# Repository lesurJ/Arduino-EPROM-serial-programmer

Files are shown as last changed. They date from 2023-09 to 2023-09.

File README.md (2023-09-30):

# Arduino-EPROM-serial-programmer

A project to program vintage EPROMs with modern Python and Arduino.

/!\ Work in progress. New version will include voltage regulators to generate the required programming voltages.

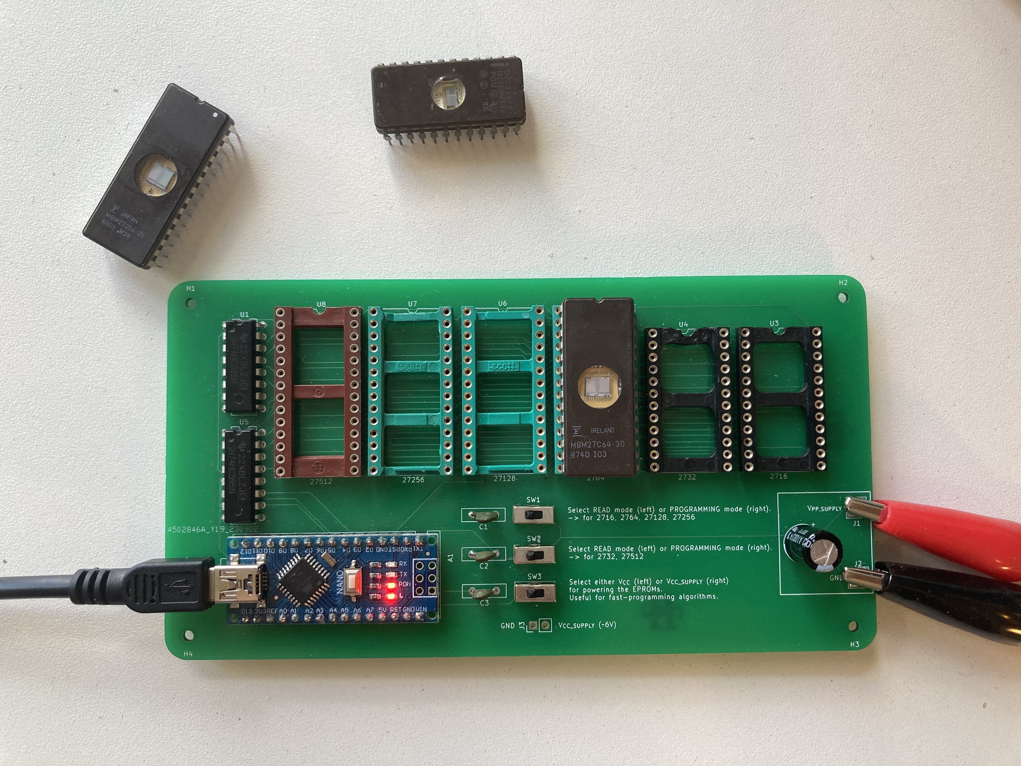
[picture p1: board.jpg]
board


## Introduction

EPROMs are found in many old devices (scopes, data logger, computer). They are very good at long term data retention. And the good thing is they can be erased and re-programmed easily (with a bit of hardware).

Unfortunately, the devices for reading and programming EPROMs are usually expensive as they are universal: they can program almost all EPROMs. I really don't need such universal programmers as I use EPROMs for my hobby and I have only a few different types of EPROM.

## Description

A serial connection is opened between the computer and the arduino. This connection is used to transfer commands (read or write) and data (memory contents or machine code).

The circuit schematic is located [here](EPROM_FLASHER/Schematic.pdf).
It is based on an Arduino Nano, two 8-bit serial-in parallel-out shift registers (ref. 74HC595) and some passive components (condensator, 3 capacitors, 3 switches). Two soldering pads are present for powering the "program pin" of the EPROMs during a write operation.

The address lines of the EPROMs are driven by the shift registers whereas their data lines are driven by 8 Arduino pins.

## Installation

* Flash the [arduino program](arduino_programmer/arduino_programmer.ino) into the Arduino Nano. Use the Arduino IDE for this.
* Get yourself the PCB. You can directly upload the [zip file](EPROM_FLASHER/GERBER/EPROM_FLASHER.zip) to PCB production services.
* Solder the components on the PCB.
* Install a SINGLE EPROM on the board.

## Usage

* Connect the Arduino to the computer.
* For reading the EPROM run

```sh
python3 main.py -t X
```

where **X** is the memory type code (see [supported EPROMs](#supported-eproms)). The EPROM contents will be written in the file [epromContents_before.txt](epromContents_before.txt).

* For programming the EPROM run

```python
python3 main.py -t X -f path-to-the-machine-code-txt
```

where **X** is the memory type code (see [supported EPROMs](#supported-eproms)) and the path is indicating where you machine code is located.
Before programming, the program will pause and ask you to apply the programming voltage on the external supply pad. It will resume once you press the ENTER key.

## Example

A machine code example is located [here](programs/machineCode.txt). It is not a binary file but a txt files containing the program bytes on separate lines.

&rarr; If I want to read the contents of a NEC 2732D EPROM, I run

```sh
python3 main.py -t 32
```

&rarr; If I want to write the program [programs/machineCode.txt](programs/machineCode.txt) in the NEC 2732D EPROM, I run

```sh
python3 main.py -t 32 -f programs/machineCode.txt
```

I can see the contents of the EPROM in the file [epromContents_before.txt](epromContents_before.txt).

## Supported EPROMs

|EPROM|memory code|Memory Size [bytes]|
|---|---|---|
|27x16|16|2048|
|27x32|32|4096|
|27x64|64|8192|
|27x128|128|16384|
|27x256|256|32768|
|27x512|512|65536|

## Warning

DO NOT HOT-SWAP EPROM!

READ CAREFULLY THE DATASHEET FOR YOUR EPROM TO CHECK THE PROGRAMMING PROCEDURE AND VOLTAGE!

## Note

This project was made with components I had laying around. I didn't have a ZIF (Zero Insertion Force) socket for the EPROMs and this is the reason why I used 6 different sockets.

To keep the board simple, the programming voltage is not generated on the board, but  by an external power supply whose wires are attached to the power supply terminals.

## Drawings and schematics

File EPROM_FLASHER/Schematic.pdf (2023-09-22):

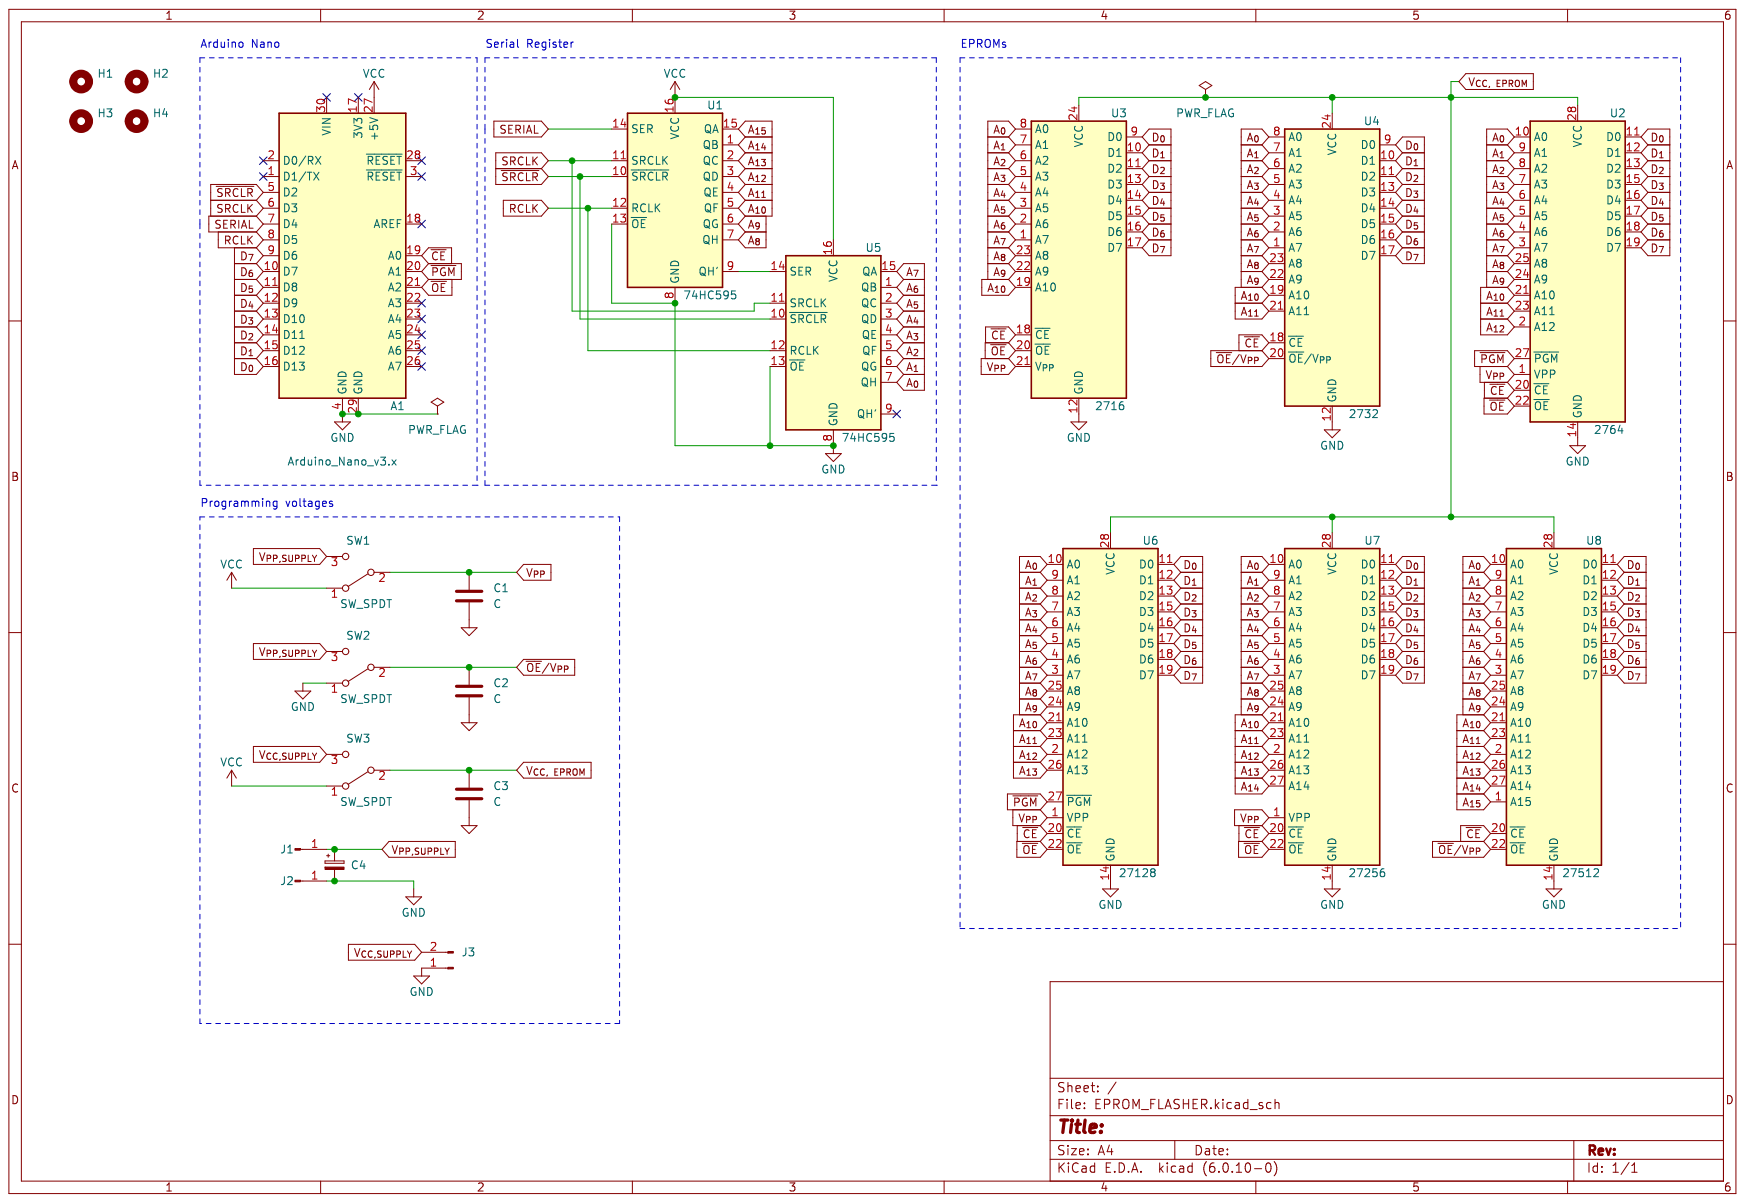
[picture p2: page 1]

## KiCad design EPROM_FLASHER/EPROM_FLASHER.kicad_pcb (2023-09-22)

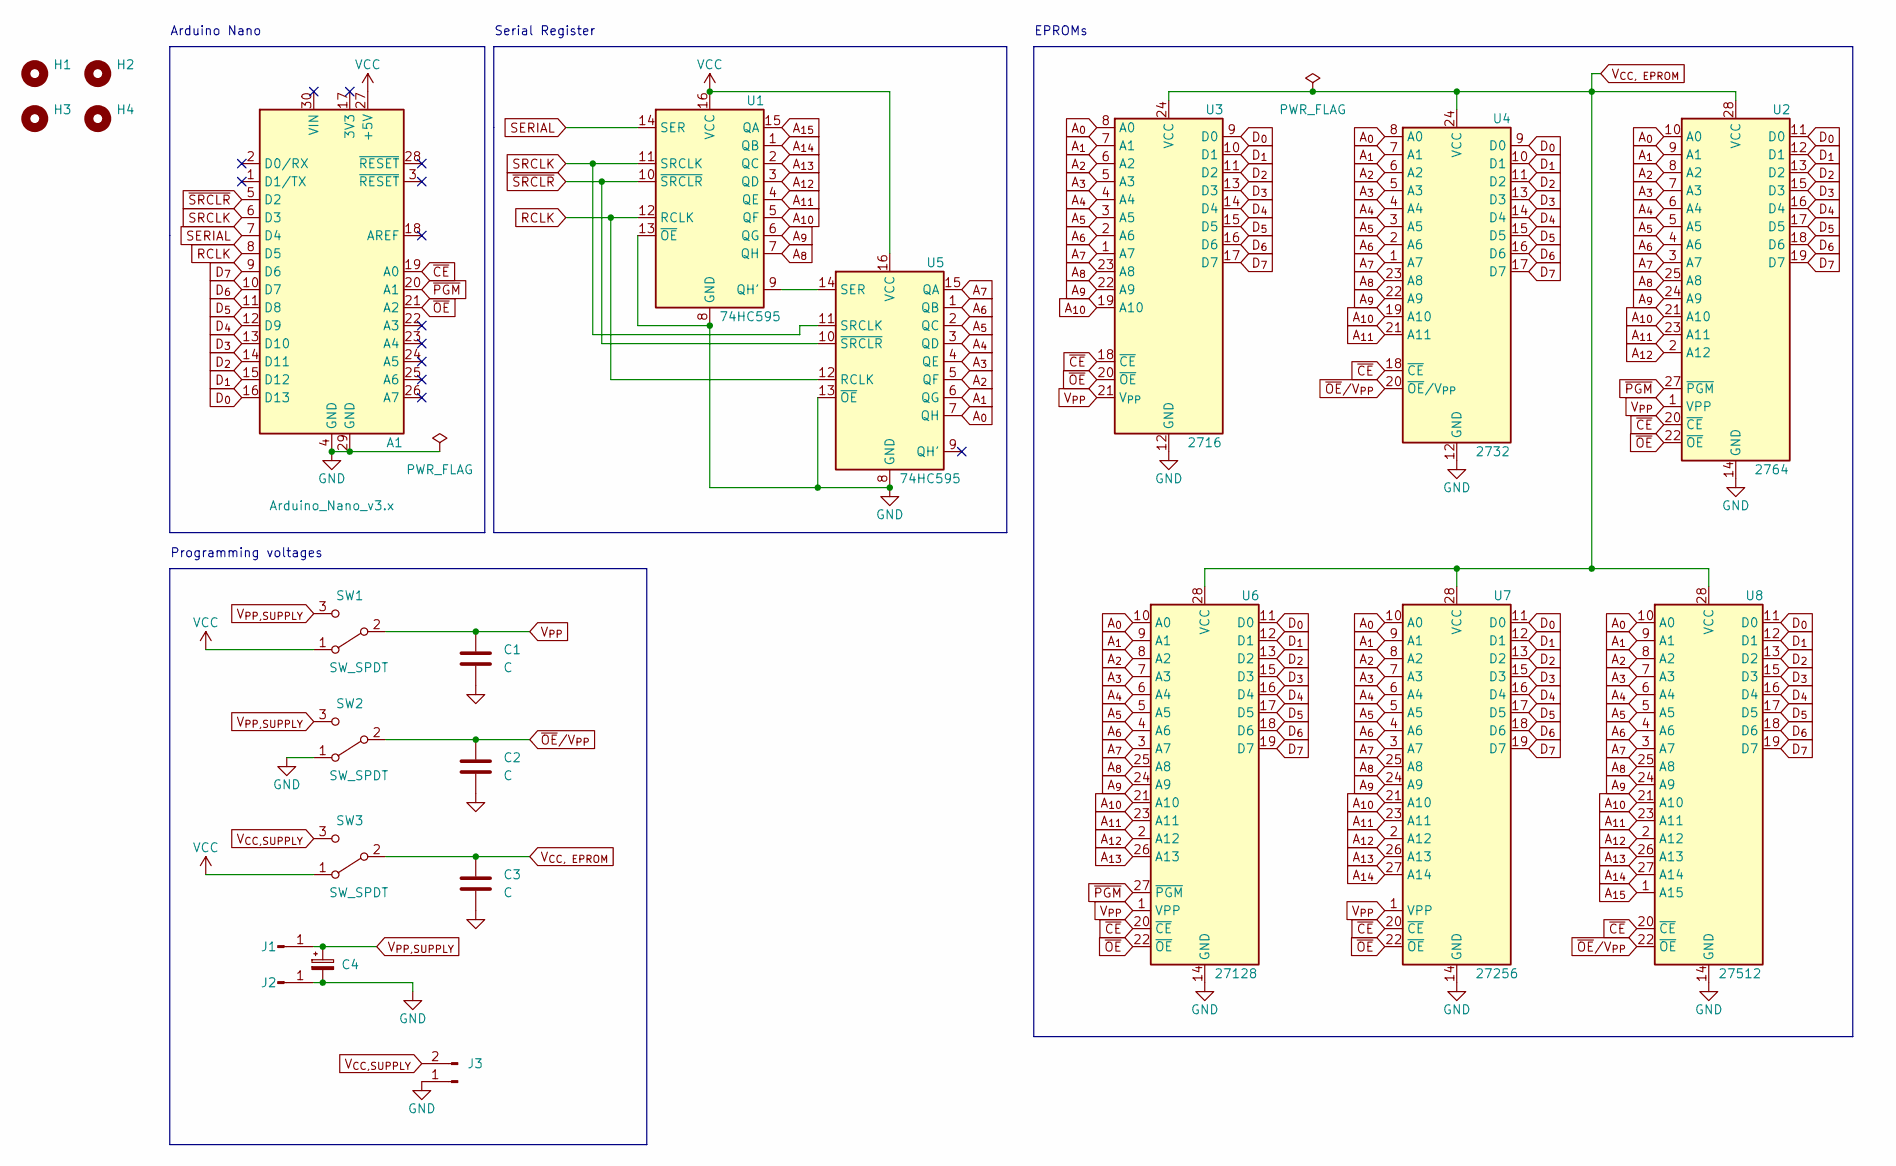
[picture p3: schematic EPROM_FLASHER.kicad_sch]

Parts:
A1: Arduino_Nano_v3.x; Arduino_Nano
C1, C2, C3: C; C_Disc_D9.0mm_W2.5mm_P5.00mm
C4: C_Polarized_Small; CP_Radial_D8.0mm_P3.50mm
H1, H2, H3, H4: MountingHole; MountingHole_2.2mm_M2
J1, J2: Conn_01x01_Male; TestPoint_Pad_4.0x4.0mm
J3: Conn_01x02_Male; PinHeader_1x02_P2.54mm_Vertical
SW1, SW2, SW3: SW_SPDT; SPDT_p2.54mm
U1, U5: 74HC595; DIP-16_W7.62mm
U2: 2764; DIP-28_W15.24mm
U3: 2716; DIP-24_W15.24mm
U4: 2732; DIP-24_W15.24mm
U6: 27128; DIP-28_W15.24mm
U7: 27256; DIP-28_W15.24mm
U8: 27512; DIP-28_W15.24mm

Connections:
A_{0}: U2.10 (A0), U3.8 (A0), U4.8 (A0), U5.7 (QH), U6.10 (A0), U7.10 (A0), U8.10 (A0)
A_{1}: U2.9 (A1), U3.7 (A1), U4.7 (A1), U5.6 (QG), U6.9 (A1), U7.9 (A1), U8.9 (A1)
A_{2}: U2.8 (A2), U3.6 (A2), U4.6 (A2), U5.5 (QF), U6.8 (A2), U7.8 (A2), U8.8 (A2)
A_{3}: U2.7 (A3), U3.5 (A3), U4.5 (A3), U5.4 (QE), U6.7 (A3), U7.7 (A3), U8.7 (A3)
A_{4}: U2.6 (A4), U3.4 (A4), U4.4 (A4), U5.3 (QD), U6.6 (A4), U7.6 (A4), U8.6 (A4)
A_{5}: U2.5 (A5), U3.3 (A5), U4.3 (A5), U5.2 (QC), U6.5 (A5), U7.5 (A5), U8.5 (A5)
A_{6}: U2.4 (A6), U3.2 (A6), U4.2 (A6), U5.1 (QB), U6.4 (A6), U7.4 (A6), U8.4 (A6)
A_{7}: U2.3 (A7), U3.1 (A7), U4.1 (A7), U5.15 (QA), U6.3 (A7), U7.3 (A7), U8.3 (A7)
A_{8}: U1.7 (QH), U2.25 (A8), U3.23 (A8), U4.23 (A8), U6.25 (A8), U7.25 (A8), U8.25 (A8)
A_{9}: U1.6 (QG), U2.24 (A9), U3.22 (A9), U4.22 (A9), U6.24 (A9), U7.24 (A9), U8.24 (A9)
A_{10}: U1.5 (QF), U2.21 (A10), U3.19 (A10), U4.19 (A10), U6.21 (A10), U7.21 (A10), U8.21 (A10)
A_{11}: U1.4 (QE), U2.23 (A11), U4.21 (A11), U6.23 (A11), U7.23 (A11), U8.23 (A11)
A_{12}: U1.3 (QD), U2.2 (A12), U6.2 (A12), U7.2 (A12), U8.2 (A12)
A_{13}: U1.2 (QC), U6.26 (A13), U7.26 (A13), U8.26 (A13)
A_{14}: U1.1 (QB), U7.27 (A14), U8.27 (A14)
A_{15}: U1.15 (QA), U8.1 (A15)
D_{0}: A1.16 (D13), U2.11 (D0), U3.9 (D0), U4.9 (D0), U6.11 (D0), U7.11 (D0), U8.11 (D0)
D_{1}: A1.15 (D12), U2.12 (D1), U3.10 (D1), U4.10 (D1), U6.12 (D1), U7.12 (D1), U8.12 (D1)
D_{2}: A1.14 (D11), U2.13 (D2), U3.11 (D2), U4.11 (D2), U6.13 (D2), U7.13 (D2), U8.13 (D2)
D_{3}: A1.13 (D10), U2.15 (D3), U3.13 (D3), U4.13 (D3), U6.15 (D3), U7.15 (D3), U8.15 (D3)
D_{4}: A1.12 (D9), U2.16 (D4), U3.14 (D4), U4.14 (D4), U6.16 (D4), U7.16 (D4), U8.16 (D4)
D_{5}: A1.11 (D8), U2.17 (D5), U3.15 (D5), U4.15 (D5), U6.17 (D5), U7.17 (D5), U8.17 (D5)
D_{6}: A1.10 (D7), U2.18 (D6), U3.16 (D6), U4.16 (D6), U6.18 (D6), U7.18 (D6), U8.18 (D6)
D_{7}: A1.9 (D6), U2.19 (D7), U3.17 (D7), U4.17 (D7), U6.19 (D7), U7.19 (D7), U8.19 (D7)
GND: A1.4 (GND), A1.29 (GND), C1.2, C2.2, C3.2, C4.2, J2.1, J3.1, SW2.1 (A), U1.8 (GND), U1.13 (~OE), U2.14 (GND), U3.12 (GND), U4.12 (GND), U5.8 (GND), U5.13 (~OE), U6.14 (GND), U7.14 (GND), U8.14 (GND)
unnamed: U1.9 (QH'), U5.14 (SER)
RCLK: A1.8 (D5), U1.12 (RCLK), U5.12 (RCLK)
SERIAL: A1.7 (D4), U1.14 (SER)
SRCLK: A1.6 (D3), U1.11 (SRCLK), U5.11 (SRCLK)
VCC: A1.27 (+5V), SW1.1 (A), SW3.1 (A), U1.16 (VCC), U5.16 (VCC)
V_{CC, EPROM}: C3.1, SW3.2 (B), U2.28 (VCC), U3.24 (VCC), U4.24 (VCC), U6.28 (VCC), U7.28 (VCC), U8.28 (VCC)
V_{CC,SUPPLY}: J3.2, SW3.3 (C)
V_{PP,SUPPLY}: C4.1, J1.1, SW1.3 (C), SW2.3 (C)
V_{PP}: C1.1, SW1.2 (B), U2.1 (VPP), U3.21 (V_{PP}), U6.1 (VPP), U7.1 (VPP)
~CE: A1.19 (A0), U2.20 (~CE), U3.18 (~CE), U4.18 (~CE), U6.20 (~CE), U7.20 (~CE), U8.20 (~CE)
~OE: A1.21 (A2), U2.22 (~OE), U3.20 (~OE), U6.22 (~OE), U7.22 (~OE)
~OE/V_{PP}: C2.1, SW2.2 (B), U4.20 (~OE/V_{PP}), U8.22 (~OE)
~PGM: A1.20 (A1), U2.27 (~PGM), U6.27 (~PGM)
~SRCLR: A1.5 (D2), U1.10 (~SRCLR), U5.10 (~SRCLR)

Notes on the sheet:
EPROMs
Serial Register
Programming voltages
Arduino Nano

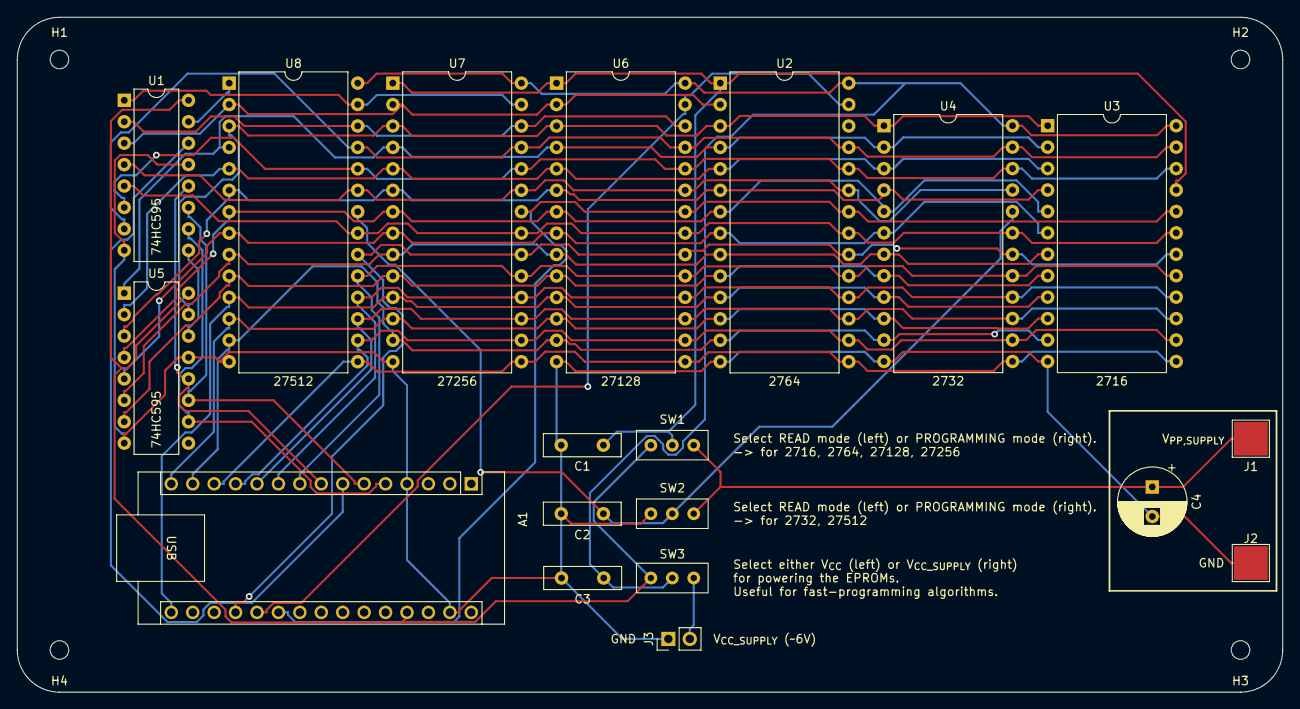
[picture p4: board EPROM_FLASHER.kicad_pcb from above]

Board: 2 copper layers, 150.0 x 80.0 mm, 23 parts (0 on the bottom side), 39 nets.

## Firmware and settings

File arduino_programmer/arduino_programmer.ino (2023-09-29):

const int nSRCLR_pin = 2;
const int SRCLK_pin = 3;
const int SERIAL_pin = 4;
const int RCLK_pin = 5;
const int msb_pin = 6;
const int lsb_pin = 13;

const int nCE_PIN = A0;
const int nPGM_PIN = A1;
const int nOE_PIN = A2;

const unsigned long baudrate = 115200;
const char start_of_message = '<';
const char end_of_message = '>';
const int read_mode = 0;
const int write_mode = 1;

const int chunk_size = 16;
byte data_buffer[chunk_size];

// === FUNCTIONS ===

void setAddress(long address)
{
    digitalWrite(RCLK_pin, LOW);
    shiftOut(SERIAL_pin, SRCLK_pin, LSBFIRST, (byte)address);
    shiftOut(SERIAL_pin, SRCLK_pin, LSBFIRST, address >> 8);
    digitalWrite(RCLK_pin, HIGH);
}

void changeDataPinMode(int mode)
{
    if (mode == read_mode)
    {
        for (int pin = msb_pin; pin <= lsb_pin; pin++)
        {
            pinMode(pin, INPUT);
        }
    }
    else if (mode == write_mode)
    {
        for (int pin = msb_pin; pin <= lsb_pin; pin++)
        {
            pinMode(pin, OUTPUT);
        }
    }
}

void changeControlPinLevels(int mode, int eprom_type)
{
    if (mode == read_mode)
    {
        digitalWrite(nCE_PIN, LOW);
        digitalWrite(nOE_PIN, LOW);
        digitalWrite(nPGM_PIN, HIGH);
    }
    else
    {
        switch (eprom_type)
        {
        case 16:
            digitalWrite(nOE_PIN, HIGH);
            digitalWrite(nCE_PIN, LOW);
            break;

        case 32:
            digitalWrite(nCE_PIN, HIGH);
            break;

        case 64:
            digitalWrite(nCE_PIN, LOW);
            digitalWrite(nOE_PIN, HIGH);
            digitalWrite(nPGM_PIN, HIGH);
            break;

        case 128:
            digitalWrite(nCE_PIN, LOW);
            digitalWrite(nOE_PIN, HIGH);
            digitalWrite(nPGM_PIN, HIGH);
            break;

        case 256:
            digitalWrite(nCE_PIN, HIGH);
            digitalWrite(nOE_PIN, HIGH);
            break;

        case 512:
            digitalWrite(nCE_PIN, HIGH);
            break;
        }
    }
}

void generateProgramPulse(int eprom_type)
{
    switch (eprom_type)
    {
    case 16:
        digitalWrite(nCE_PIN, HIGH);
        delay(50);
        digitalWrite(nCE_PIN, LOW);
        break;

    case 32:
        digitalWrite(nCE_PIN, LOW);
        delay(50);
        digitalWrite(nCE_PIN, HIGH);
        break;

    case 64:
        digitalWrite(nPGM_PIN, LOW);
        delay(50);
        digitalWrite(nPGM_PIN, HIGH);
        break;

    case 128:
        digitalWrite(nPGM_PIN, LOW);
        delayMicroseconds(100);
        digitalWrite(nPGM_PIN, HIGH);
        break;

    case 256:
        digitalWrite(nCE_PIN, LOW);
        delayMicroseconds(100);
        digitalWrite(nCE_PIN, HIGH);
        break;

    case 512:
        digitalWrite(nCE_PIN, LOW);
        delayMicroseconds(100);
        digitalWrite(nCE_PIN, HIGH);
        break;
    }
}

String waitForSerialMessage(void)
{
    String message = "";
    char current_char = ' ';
    bool received_message = false;

    while (!received_message)
    {
        while (Serial.available() > 0)
        {
            current_char = Serial.read();
            if (current_char == start_of_message)
            {
                message = "";
            }
            else if (current_char == end_of_message)
            {
                received_message = true;
                break;
            }
            else
            {
                message += String(current_char);
            }
        }
    }
    return message;
}

byte readMemoryAtAddress(long address)
{
    setAddress(address);
    delayMicroseconds(1); // typical access time is 200ns for EPROM
    byte data = 0;
    for (int pin = msb_pin; pin <= lsb_pin; pin++)
    {
        data = (data << 1) + digitalRead(pin);
    }
    return data;
}

void readMemory(int eprom_type, long memory_size)
{
    changeDataPinMode(read_mode);
    changeControlPinLevels(read_mode, eprom_type);

    long bytes_read = 0;
    bool read_is_done = false;
    while (!read_is_done)
    {
        Serial.print(start_of_message);
        for (int addr = 0; addr < chunk_size; addr++)
        {
            byte data = readMemoryAtAddress(bytes_read + addr);
            Serial.println(data);
        }
        Serial.println(end_of_message);

        bytes_read += chunk_size;
        read_is_done = (bytes_read == memory_size);
    }
    Serial.println("<DONE>");
}

void writeMemory(int eprom_type, long program_size)
{
    changeDataPinMode(write_mode);
    changeControlPinLevels(write_mode, eprom_type);

    Serial.println("<WRITE-READY>");

    long data_index = 0;
    long current_address = 0;
    bool transfer_is_done = false;
    while (!transfer_is_done)
    {
        int rlen = Serial.readBytes(data_buffer, chunk_size);
        for (int data_addr = 0; data_addr < rlen; data_addr++)
        {
            current_address = data_index + data_addr;
            setAddress(current_address);
            delayMicroseconds(2); // typical adress and data setup time
            for (int pin = lsb_pin; pin >= msb_pin; pin--)
            {
                digitalWrite(pin, data_buffer[data_addr] & 1);
                data_buffer[data_addr] >>= 1;
            }
            generateProgramPulse(eprom_type);
        }

        data_index += rlen;
        transfer_is_done = (data_index == program_size);
        Serial.println("<CONTINUE>");
    }
    Serial.println("<DONE>");
}

// === END OF FUNCTIONS ===

void setup()
{
    Serial.begin(baudrate);

    pinMode(nSRCLR_pin, OUTPUT);
    pinMode(SRCLK_pin, OUTPUT);
    pinMode(SERIAL_pin, OUTPUT);
    pinMode(RCLK_pin, OUTPUT);
    pinMode(nCE_PIN, OUTPUT);
    pinMode(nPGM_PIN, OUTPUT);
    pinMode(nOE_PIN, OUTPUT);

    digitalWrite(nSRCLR_pin, HIGH);
    digitalWrite(nCE_PIN, LOW);
    digitalWrite(nOE_PIN, LOW);
    digitalWrite(nPGM_PIN, HIGH);

    while (!Serial)
    {
        delay(10);
    }

    Serial.println("<INIT>");
}

void loop()
{
    String message = waitForSerialMessage();
    int idx = message.indexOf("|");
    if (idx != -1)
    {
        int eprom_type = message.substring(0, idx).toInt();
        String command = message.substring(idx + 1);

        if (command.startsWith("R"))
        {
            long memory_size = command.substring(1).toInt();
            readMemory(eprom_type, memory_size);
        }
        else if (command.startsWith("W"))
        {
            long program_size = command.substring(1).toInt();
            writeMemory(eprom_type, program_size);
        }
    }
}

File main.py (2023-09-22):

import argparse
import os
import time
import difflib

from serialConnector import SerialConnector

def configureParser():
    parser = argparse.ArgumentParser(
        prog="main.py",
        description="This program read and write vintage EPROMs with the help of Arduino.",
    )
    parser.add_argument(
        "-t",
        "--memory_type",
        type=int,
        required=True,
        choices=[16, 32, 64, 128, 256, 512],
        help="the memory type code (e.g 32 for 27x32 memories)",
    )
    parser.add_argument(
        "-f",
        "--filename",
        type=str,
        help="the name of the machine code to flash on EPROM (.txt); all bytes must be on different lines.",
    )
    return parser.parse_args()

def getProgramCode(machine_code_file):
    with open(f"{machine_code_file}", "r") as f:
        lines = f.readlines()
    programCode = [int(item.strip(), 2) for item in lines]
    return (
        len(programCode),
        programCode,
    )

def saveDataToFile(data, filename):
    data = data.split(sep="\r\n")
    with open(filename, "w") as f:
        for d in data:
            if d != "":
                f.write(f"{int(d):08b}\n")

def readMemory(memoryType, filename):
    print("> Reading EPROM:   0%", end="\r")

    memorySize = memoryType * 128 # size in bytes = type * 1024 / 8
    sc.sendCode(f"{memoryType}|R{memorySize}")
    t1 = time.time()

    epromContents = ""
    readIsDone = False
    readBytes = 0
    while not readIsDone:
        data = sc.waitForSerialData()
        if data == "DONE":
            readIsDone = True
            print(f"> Reading EPROM: 100%, elapsed time: {time.time() - t1:6.2f}")
        else:
            epromContents += data
            readBytes += chunkSize
        progress = 100 * readBytes / memorySize
        print(f"> Reading EPROM: {progress:3.0f}%, elapsed time: {time.time() - t1:6.2f}[s].", end="\r")

    saveDataToFile(epromContents, filename)

def writeMemory(memoryType, programSize, programCode):
    print("> Programming EPROM:   0%", end="\r")
    sc.sendCode(f"{memoryType}|W{programSize}")
    t1 = time.time()

    sc.waitForCode("WRITE-READY")
    i = -1
    for i in range(programSize // chunkSize):
        progress = 100 * (i * chunkSize / programSize)
        print(f"> Programming EPROM: {progress:3.0f}%, elapsed time: {time.time() - t1:6.2f}[s].", end="\r")
        sc.sendBytes(bytearray(programCode[chunkSize * i : chunkSize * (i + 1)]))
        sc.waitForCode("CONTINUE")

    sc.sendBytes(bytearray(programCode[chunkSize * (i + 1) :]))
    sc.waitForCode("DONE")
    print(f"> Programming EPROM: 100%, elapsed time: {time.time() - t1:6.2f}[s].")

def verifyProgramming(input_file):
    print("> Verifying program.")
    output_file = "epromContents_after.txt"

    with open(input_file, "r") as f:
        input_lines = f.readlines()

    with open(output_file, "r") as f:
        output_lines = f.readlines()[: len(input_lines)]
        output_lines[-1] = output_lines[-1].replace("\n", "")

    error = False
    for l in difflib.unified_diff(
        input_lines, output_lines, fromfile=input_file, tofile=output_file
    ):
        print(l)
        error = True

    if not error:
        print("> Programming success!")
    else:
        print("> Programming failure!")

if __name__ == "__main__":
    args = configureParser()
    chunkSize = 16 # how many bytes to handle at once (read or write)

    print("=== Arduino EPROM Serial Programmer ===")
    print("Make sure that a single EPROM is connected on the PCB.")
    print("Set the programming voltage (Vpp) as specified in the datasheet.")

    folder = "/dev/"
    serialPort = [
        item for item in os.listdir(folder) if item.startswith("tty.usbserial")
    ]

    if args.filename is not None:
        programSize, programCode = getProgramCode(args.filename)
        print(f"-> located machine code. Program size: {programSize} bytes.")

    sc = SerialConnector(folder + serialPort[0])
    if sc.connect():
        print(f"-> arduino connected on serial port {serialPort[0]}.")
        sc.waitForCode("INIT") # wait for arduino to initialize

        # 1. Read EPROM
        readMemory(args.memory_type, "epromContents_before.txt")

        # 2. Write EPROM
        if args.filename is not None:
            _ = input("> Apply programming voltage (toggle appropriate switch) and press ENTER.")
            writeMemory(args.memory_type, programSize, programCode)

            # 3. Read EPROM
            _ = input("> Remove programming voltage (toggle appropriate switch) and press ENTER.")
            readMemory(args.memory_type, "epromContents_after.txt")

            # 4. Verify programming
            verifyProgramming(args.filename)

    else:
        print("Unable to find/access selected serial port!")

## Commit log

2023-02-01 fixed bug when program size was smaller than chunksize
    [main.py]
2023-05-21 added Kicad project
    [2732FlasherBoard.kicad_pcb, 2732FlasherBoard.kicad_sch]
2023-09-21 new arduino program, handle different memory type
2023-09-21 changed keyword, fixed bug related to program size (now passed to function); pin levels for each eprom type, added setup time delay
    [arduino_programmer.ino]
2023-09-21 changed memory_size and program_size to long type (bug: memory size > 32765 bytes won't be represented correctly in an int)
    [arduino_programmer.ino]
2023-09-22 added last version of pcb
    [2732FlasherBoard.kicad_pcb, 2732FlasherBoard.kicad_sch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]
